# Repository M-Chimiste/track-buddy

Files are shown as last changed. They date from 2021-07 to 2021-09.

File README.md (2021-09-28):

# track-buddy
Arduino based head tracker with the BNO08X IMU.

## Hardware
Track Buddy has a very small BOM from an electronics perspective.  It requires an Arduino Pro Micro, a BNO080, and a tactile switch.  The tactile switch is wired into pin 10 and attached to the ground of the Pro Micro. I used a 6mm x 6mm x 9mm one I had lying around, but realistically anything longer than 4mm should work (the top case thickness is ~3mm when printed). The BNO080 is wired to the Pro Micro as follows:

|Pro Micro Pin|BNO080 Pin|
|-----|-----|
|VIN |VIN|
|GND|GND|
|PIN 2|SDA|
|PIN 3|SCL|

I didn't use a PCB for any of the connections.  All connections were soldered in place with wire.  I used some heat shrink tubing on the tactile switch to make sure it wouldn't short anything.

Note on the MK2 and M1.5 variants: Instead of one button there are two buttons both wired to ground and two open digital pins (code has 9,10).  One button has a pin going to ground and another wire connecting it to the other button to share a common ground.  Due to the number of ground pins on the pro micro you could simply just wired each button to a unique ground pin on the Arduino.  These buttons are used for added functionality around pausing tracking updates (for filming on games like DCS) and the original tare functionality.

## Housing
Housing is completely 3D printed.  Original housing was created with a QIDI Print X-Plus with PLA filament at 35% infill and supports around the usb socket (but realistically anything above 20% should work with no issues).  Almost any 3D printer should be sufficient for printing the shell.  In addition to the 3D printed parts you also need four M2 nuts and four M2 screws.  The M2 nuts were bonded to the 3D printed housing with a small amount of epoxy (I like to use JB Weld Kwik, but any epoxy should do).  After bonding the nuts you can affix the tactile switch to the top of the cover using some hot glue (or other adhesive, though I didn't need to use any since everything fit quite snug without it).

Note on the MK2 and MK1.5 variants:  On these variants I changed the parts list very slightly.  Additionally, I stopped using this he M2 nuts being bonded to the shell.  Instead, I purchased some M2 brass threaded inserts which I used a soldering iron to melt into the shell.  It provides for a cleaner looking finished product.

## Software

Example boards.txt is included now so that you can have track buddy called track buddy on your PC's USB HID.  I might package this up into a custom hardware folder that you can use in the future without modifying your boards.txt, but it is not currently a priority.

Arduino IDE 1.8.15 was used for flashing the pro micro board.  Make sure you install the IDE and all the Arduino drivers.  Install the Joystick library and the Sparkfun BNO080 library.  Select the Leonardo Board and the COM port of your board and hit upload.

## Configuring with OpenTrack

Track Buddy is meant to be used in conjunction with the OpenTrack software.  There are a lot of tutorials online that show you how to set up OpenTrack and adjust curves for playing your games, so I won't get into that here.  What I will provide is how to get yaw/pitch/roll into OpenTrack to get you going.

First: Make sure that you select your input as Joystick input and select the appropriate device (Either Arduino Leonardo or Track Buddy depending on how you flashed it).

Second: Configure your mapping as follows:
|Mapping|Value|
|-----|-----|
|X|Disabled|
|Y|Disabled|
|Z|Disabled|
|Yaw|Joystick Axis #7|
|Pitch|Joystick Axis #2|
|Roll|Joystick Axis #3|

For all other settings (output and filter), I left them as the default values (i.e. didn't touch them).  I do not plan to try to implement X,Y,Z, but I know there are ways to pseudo implement them.  Mainly, I don't like them when playing flight sims, but that's just my personal preference (feel free to fork and implement them).

After configuration put on your headset, make sure you are facing forward and click start.  If you find you are drifting (I've not have this problem yet) face the direction you want forward to be and click the button on the top of Track Buddy to internally offset for the drift.  That said, because the BNO080 has an internal compass I've found that I don't see much if any drift while playing, even for extended periods of time.

## SPECIAL IMPORTANT NOTE
BNO080 has an internal compass.  Don't put Track Buddy too close to a magnetic source (e.g. headphone speaker) or you may get undesirable behavior.  This is because the device uses the compass in order to help mitigate drift.

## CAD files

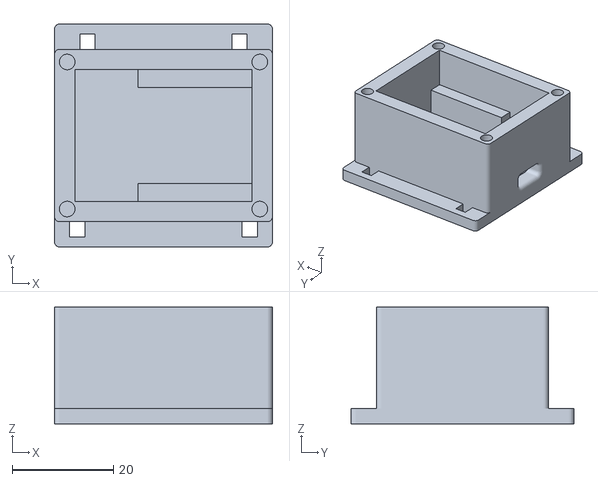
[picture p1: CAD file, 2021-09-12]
stl/track buddy mk2/track_buddy_mk2_bottom.stl
43.0 x 44.0 x 23.0

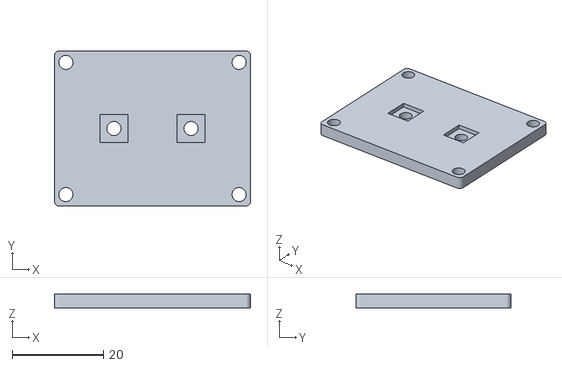
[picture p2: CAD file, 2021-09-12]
stl/track buddy mk2/track_buddy_mk2_top.stl
43.0 x 34.0 x 3.00

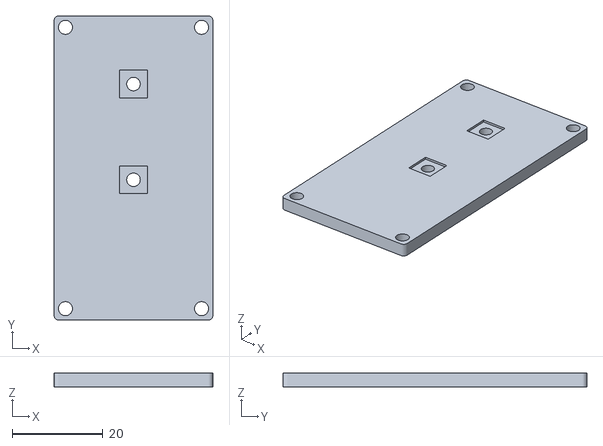
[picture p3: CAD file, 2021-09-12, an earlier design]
stl/track buddy mk1/track_buddy_top_mk15.stl
35.0 x 67.0 x 3.00

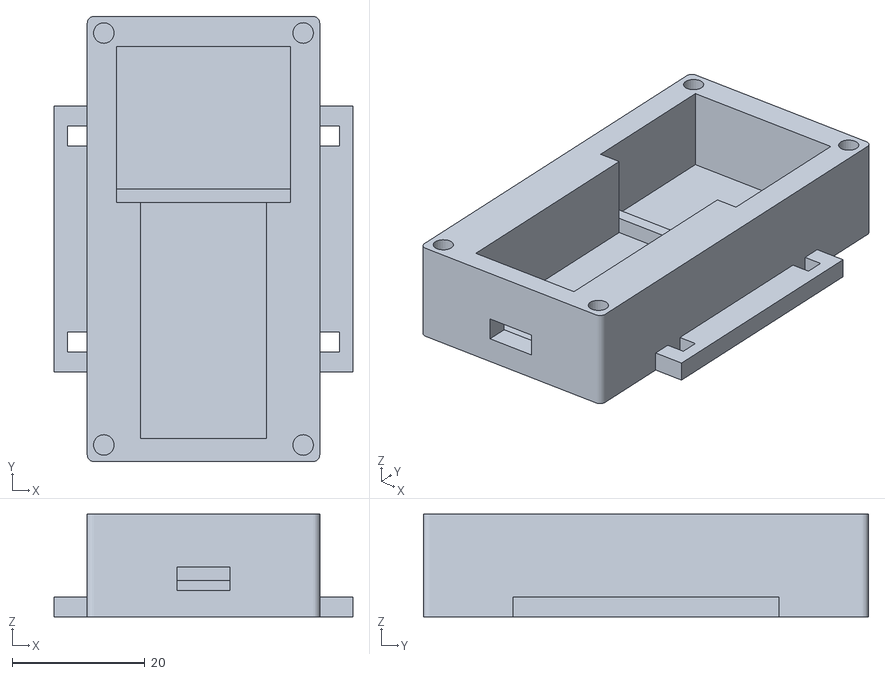
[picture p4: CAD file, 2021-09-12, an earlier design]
stl/track buddy mk1/track_buddy_bottom_mk15.stl
45.0 x 67.0 x 15.5

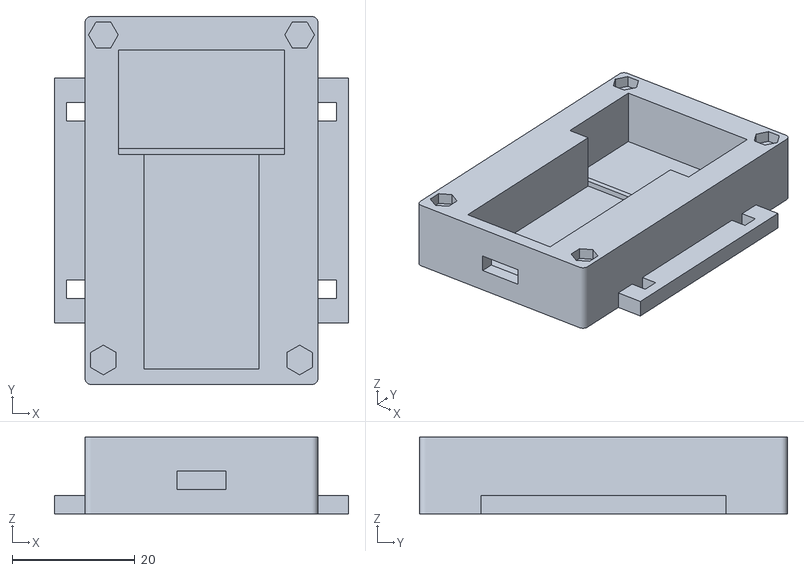
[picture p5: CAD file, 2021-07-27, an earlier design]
stl/track buddy mk1/track-buddy-base-mk1.stl
48.0 x 60.0 x 12.5

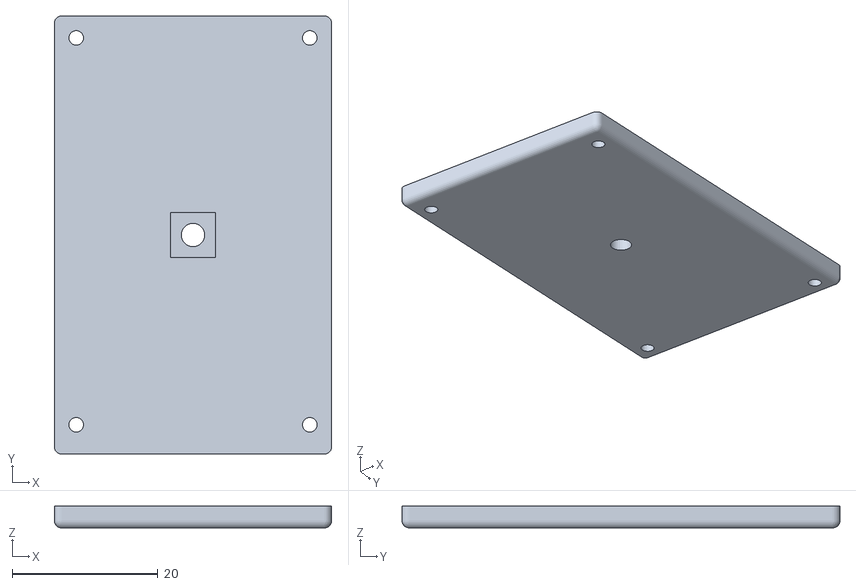
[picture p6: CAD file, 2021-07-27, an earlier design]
stl/track buddy mk1/track-buddy-top-mk1.stl
38.0 x 60.0 x 3.00

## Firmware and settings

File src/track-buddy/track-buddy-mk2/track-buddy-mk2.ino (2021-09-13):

// Track Buddy Firmware Mk2
// Author: Christian Merrill
// License: MIT 2.0
// Version: 0.2
// Tested on Arduino Pro Micro with BNO080 and IDE 1.8.15
// Changes in 0.2: Removed tare logic to opt for a joystick button press.
// This allows for using native OpenTrack "center" feature which is more preferable.
// Changed rotation vector to game rotation vector.

#include <Wire.h>
#include <Joystick.h>
#include <SparkFun_BNO080_Arduino_Library.h>


// You can use ANY of the pins for the buttons for the exception of the SDA and SCL pins
// You can even change the arrangement of the buttons through updating these definitions (e.g. you wanted tare in back versus front etc)
#define tareButton 10
#define pauseButton 9

int currentTareState = 0;
int currentPauseState;
int lastTareState = 0;
int lastPauseState = LOW;
int lastPauseCHGState = LOW;
int xAxis_ = 0;
int yAxis_ = 0;
int rzAxis_ = 0;

float roll = 0;
float yaw = 0;
float pitch = 0;


bool paused = false;
bool tare = false;

unsigned long lastPauseDebounceTime = 0;
unsigned long lastTareDebounceTime = 0;

const bool debug = false;  // enables serial printing if True (outputs degrees not ints)
const bool initAutoSendState = false;  // used to automatically send joystick state
const int smoothing = 1023; // used to map roll/pitch/yaw to an integer value 
const int debounce = 1;  // delay in ms for debouncing
const int sendRate = 1; // send rate in ms for the BNO080 IMU;
const int pauseDebounceTime = 50;



// Initalize the Joystick Data Structure
//The Joystick is defined in the following setup:
//Joystick(Joystick HID ID, Joystick Type, Button Count, Hat Switch Count, Include X, Include Y, Include Z, Include Rx, Include Ry, Include Rz, Include Rudder, Include Throttle, Include Accelerator, Include Brake, Include Steering
//Joystick HID ID: A Hex value identifier for HID Device Recognition (default: 0x03). DO NOT USE 0x01 or 0x02
//Joystick type: Define the type of joystick from the types supported. Types: DEFAULT Joystick (0x04 or JOYSTICK_TYPE_JOYSTICK), Gamepad (0x05 or JOYSTICK_TYPE_GAMEPAD), Multi-Axis Controller (0x08 or JOYSTICK_TYPE_MULTI_AXIS)
//Button Count: Number of Buttons shown to HID system (default: 32)
//Hat Switch Count: Number of Hat Switches, max 2. (default:2)
//Include X Axis: Determines whether the X axis is avalible for used by the HID system, defined as a bool value (default:true)
//Include Y Axis: Determines whether the Y axis is avalible for used by the HID system, defined as a bool value (default:true)
//Include Z Axis: Determines whether the Z axis is avalible for used by the HID system, defined as a bool value (default:true)
//Include Rx Axis: Determines whether the X Rotational axis is avalible for used by the HID system, defined as a bool value (default:true)
//Include Ry Axis: Determines whether the Y Rotational axis is avalible for used by the HID system, defined as a bool value (default:true)
//Include Rz Axis: Determines whether the Z Rotational axis is avalible for used by the HID system, defined as a bool value (default:true)
//Include Rudder: Determines whether a Rudder axis is avalible for used by the HID system, defined as a bool value (default:true)
//Include Throttle: Determines whether a Throttle axis is avalible for used by the HID system, defined as a bool value (default:true)
//Include Accelerator: Determines whether an Accelerator axis is avalible for used by the HID system, defined as a bool value (default:true)
//Include Brake: Determines whether a Brake axis is avalible for used by the HID system, defined as a bool value (default:true)
//Include Steering: Determines whether a Steering axis is avalible for used by the HID system, defined as a bool value (default:true)

Joystick_ Joystick(0x16, JOYSTICK_TYPE_JOYSTICK, 1, 0, true, true, false, false, false, true, false, false, false, false, false);  //Make sure that hex value is unique, update as needed.

BNO080 BNO080_;
// Constants for Program


void setup()
{
  if (debug == true) {
    Serial.begin(115200);
    Serial.println();
    Serial.println("Track-buddy Mk2 v0.1. Debug mode enabled.");
  }

  Wire.begin();
  pinMode(tareButton, INPUT_PULLUP);
  pinMode(pauseButton, INPUT_PULLUP);
  
  Joystick.begin();
  
  if (BNO080_.begin() == false) {
     Serial.println(F("BNO080 not detected. Check connection and try again."));
     while (1);
   }
  
  Wire.setClock(400000);

  BNO080_.enableGameRotationVector(sendRate); //Send data update every 30ms
  
  if (debug == true) {
    Serial.println(F("BNO080 detected and rotation vector has been enabled"));
    Serial.println(F("Output in form of degrees roll, pitch, yaw"));
  }
}

int setButtonState(int currentButtonState, int previousButtonState, int button){
  // Function to update button states and update the joystick
  int newButtonState;
  if (currentButtonState != previousButtonState){
    Joystick.setButton(button, currentButtonState);
    newButtonState = currentButtonState;
    return newButtonState;
  }
  else {
    newButtonState = previousButtonState;
    return newButtonState;
  }
}

void loop()
{

  if (BNO080_.dataAvailable() == true)
  {
    
    if (paused != true){
      // Get raw values from sensor, example taken from Spark Fun library
      roll = (BNO080_.getRoll()) * 180.0 / PI; // Convert roll to degrees
      pitch = (BNO080_.getPitch()) * 180.0 / PI; // Convert pitch to degrees
      yaw = (BNO080_.getYaw()) * 180.0 / PI; // Convert yaw / heading to degrees


    
      // Check for tare button push
      currentTareState = !digitalRead(tareButton);
      lastTareState = setButtonState(currentTareState, lastTareState, 0);


      // debouncing not necessary for tare button
//      if (currentTareState != lastTareState) {
//        // set current axis values as offset from internal measures of current values
//        xOffset = (BNO080_.getRoll()) * 180.0 / PI;
//        yOffset = (BNO080_.getPitch()) * 180.0 / PI;
//        rzOffset = (BNO080_.getYaw()) * 180.0 / PI;
//    
//    }
    }
    
   

    // Convert roll/pitch/yaw into integers for sending to joystick axis values
    xAxis_ = map(roll, -180, 180, 0, smoothing);
    yAxis_ = map(pitch, -180, 180, 0, smoothing);
    rzAxis_ = map(yaw, -180, 180, 0, smoothing);

    // Set axis values to joystick
    Joystick.setXAxis(xAxis_);
    Joystick.setYAxis(yAxis_);
    Joystick.setRzAxis(rzAxis_);
  
    
    
    currentPauseState = digitalRead(pauseButton);
    
    if (currentPauseState != lastPauseCHGState) {
      lastPauseDebounceTime = millis();
      lastPauseCHGState = currentPauseState;
    }

    if ((millis() - lastPauseDebounceTime) > pauseDebounceTime) {
      if (lastPauseState == HIGH && currentPauseState == LOW) {
        paused = !paused;
      }


      lastPauseState = currentPauseState;
    }

    
    
  if (debug == true){
      Serial.print(roll, 1);
      Serial.print(F(","));
      Serial.print(pitch, 1);
      Serial.print(F(","));
      Serial.print(yaw, 1);
      Serial.print(F(","));
      if (paused == true) {
        Serial.print("Paused");
      }
      else {
        Serial.print("Running");
      }
      Serial.println();
    }
    
    Joystick.sendState();
    delay(debounce); // Delay for debouncing
  } 
}

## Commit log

2021-07-27 update track-buddy.ino typo
2021-08-26 Update and rename track-buddy.ino to track-buddy-mk1.ino
2021-08-27 Updated STL for mk1
    [track-buddy-base-mk1.stl, track-buddy-top-mk1.stl]
2021-09-01 Added STLs
    Added STLs for track buddy mk2 and mk1.5. Track Buddy mk 1.5 is just a small remix of the original track buddy mk1 with the dual button functionality.
    [track_buddy_bottom_mk15.stl, track_buddy_mk2_bottom.stl, track_buddy_mk2_top.stl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]
2021-09-01 Update README.md
    Added information about the MK2 and MK1.5 track buddy variants
